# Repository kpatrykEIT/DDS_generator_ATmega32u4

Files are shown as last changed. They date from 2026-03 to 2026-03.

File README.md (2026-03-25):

# DDS_generator_ATmega32u4

Periodic waveform generator project based on Direct Digital Synthesis (DDS). The system utilizes an ATmega32u4 microcontroller and a TLC7524C DAC. Developed low-level firmware in C using direct register manipulation. Designed the PCB in KiCad.

<table>
  <tr>
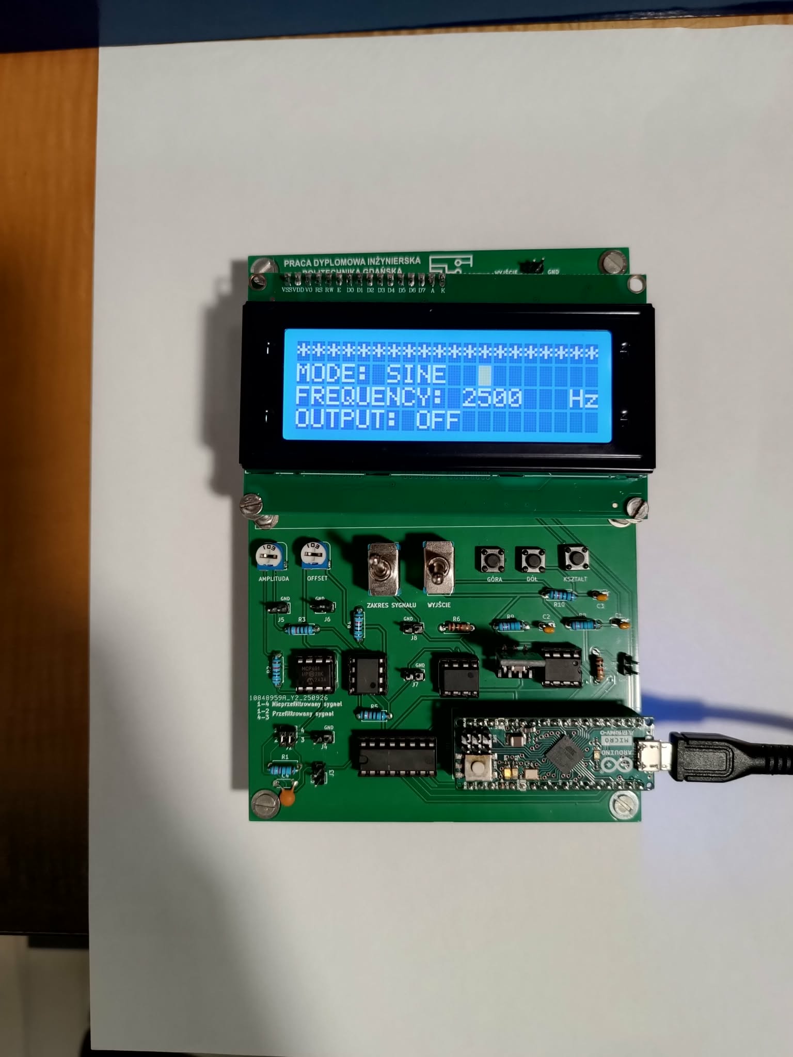
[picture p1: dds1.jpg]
    <td></td>
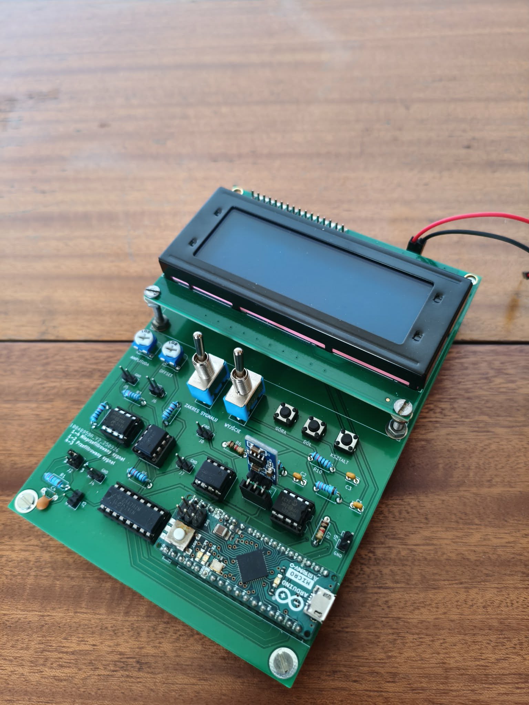
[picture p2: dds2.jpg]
    <td></td>
  </tr>
  <tr>
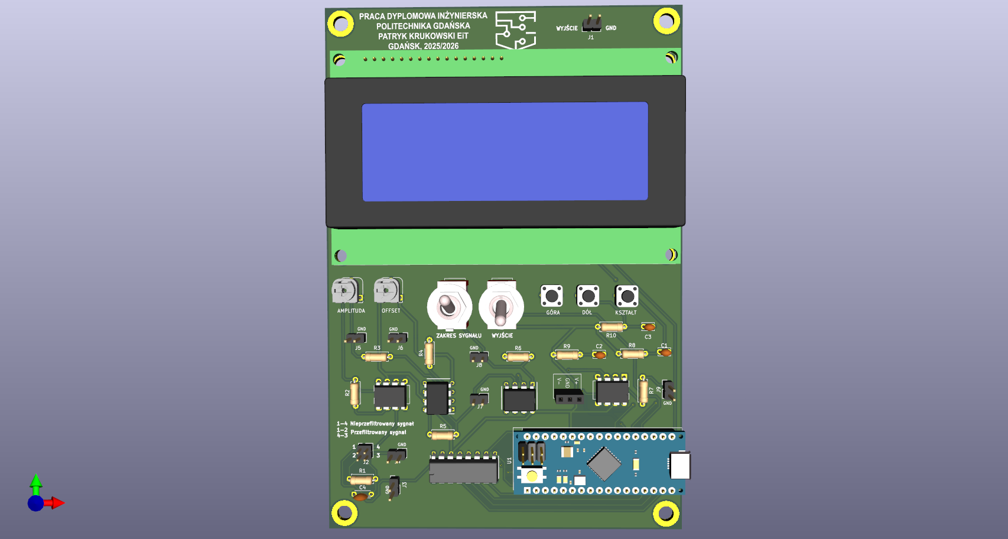
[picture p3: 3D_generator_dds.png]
    <td></td>
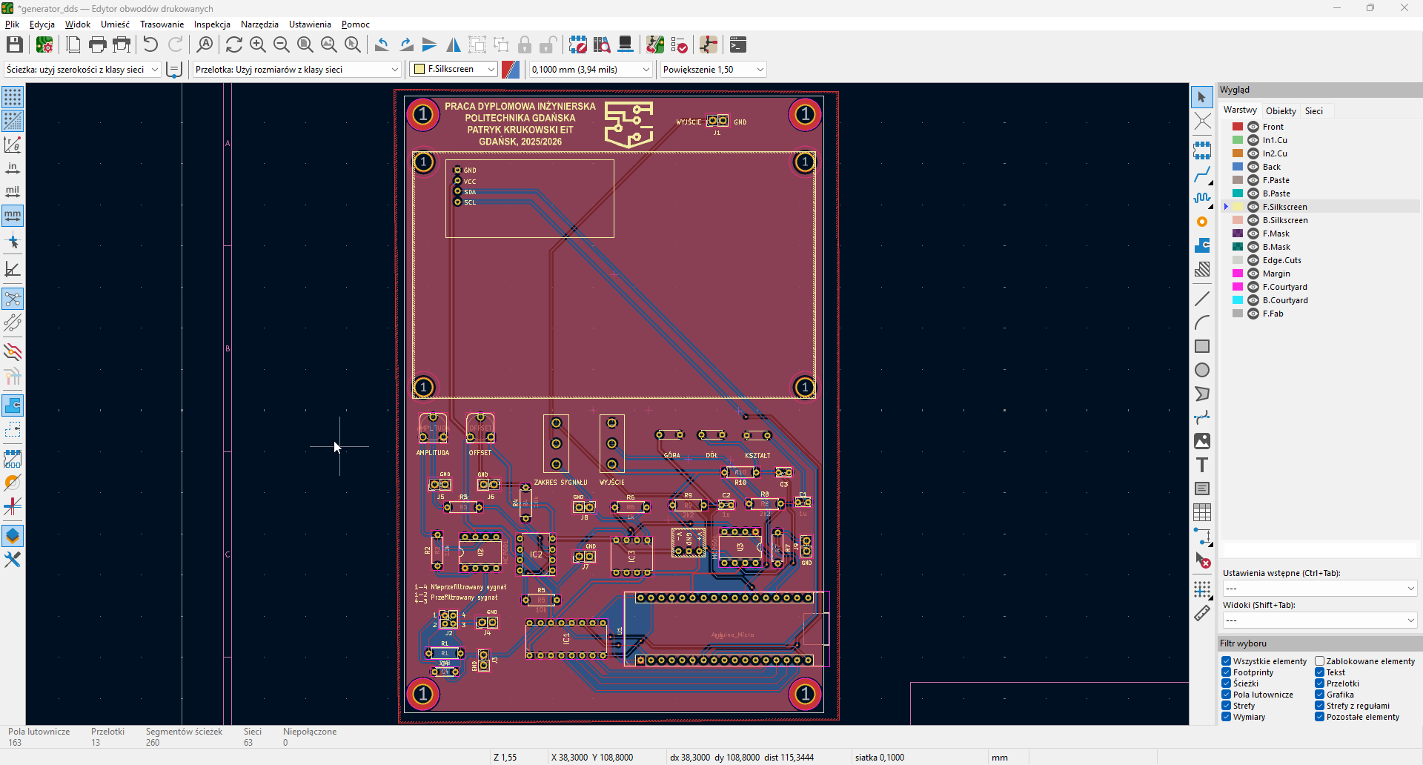
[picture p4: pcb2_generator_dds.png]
  <td></td>
  </tr>
</table>

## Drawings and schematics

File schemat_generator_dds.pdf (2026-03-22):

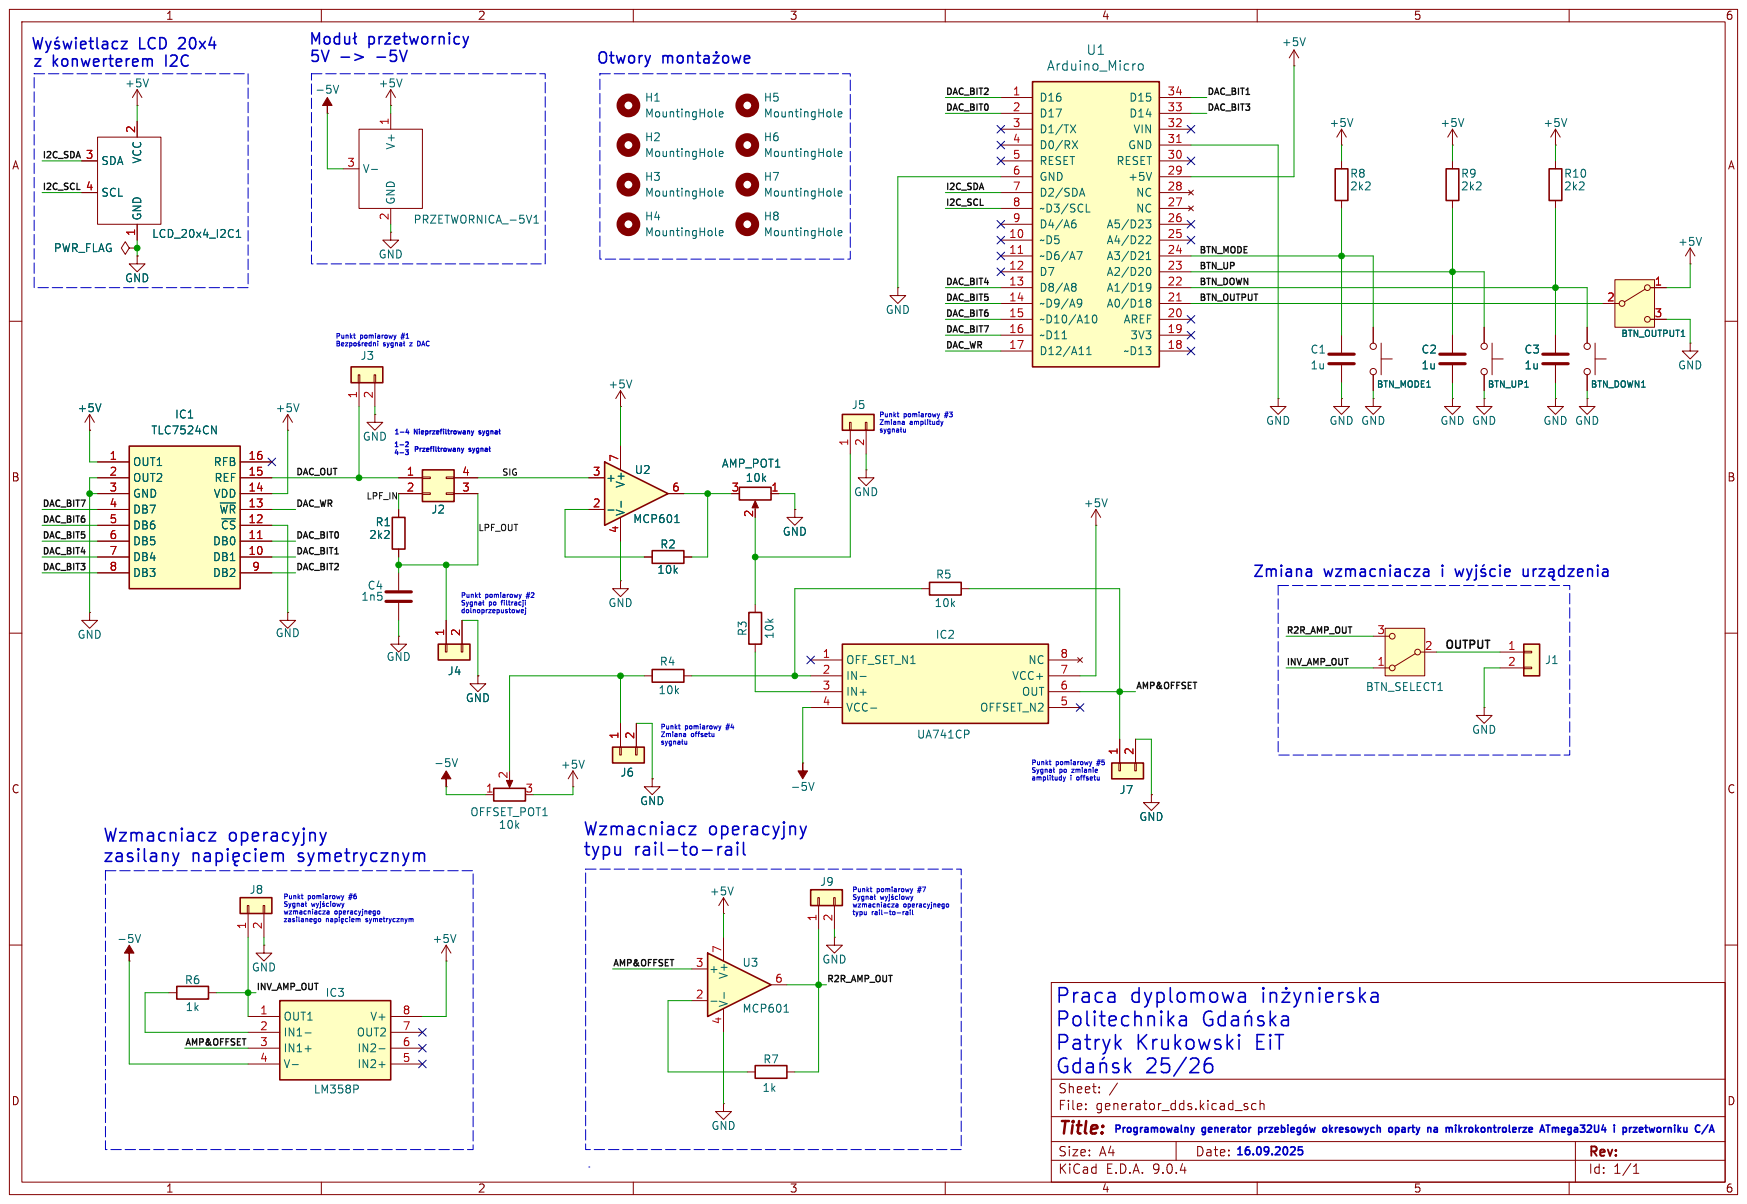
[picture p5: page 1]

typu rail-to-rail

Politechnika þÿGdaDska
Patryk Krukowski EiT
Id: 1/1 Title: File: generator_dds.kicad_sch Sheet: /

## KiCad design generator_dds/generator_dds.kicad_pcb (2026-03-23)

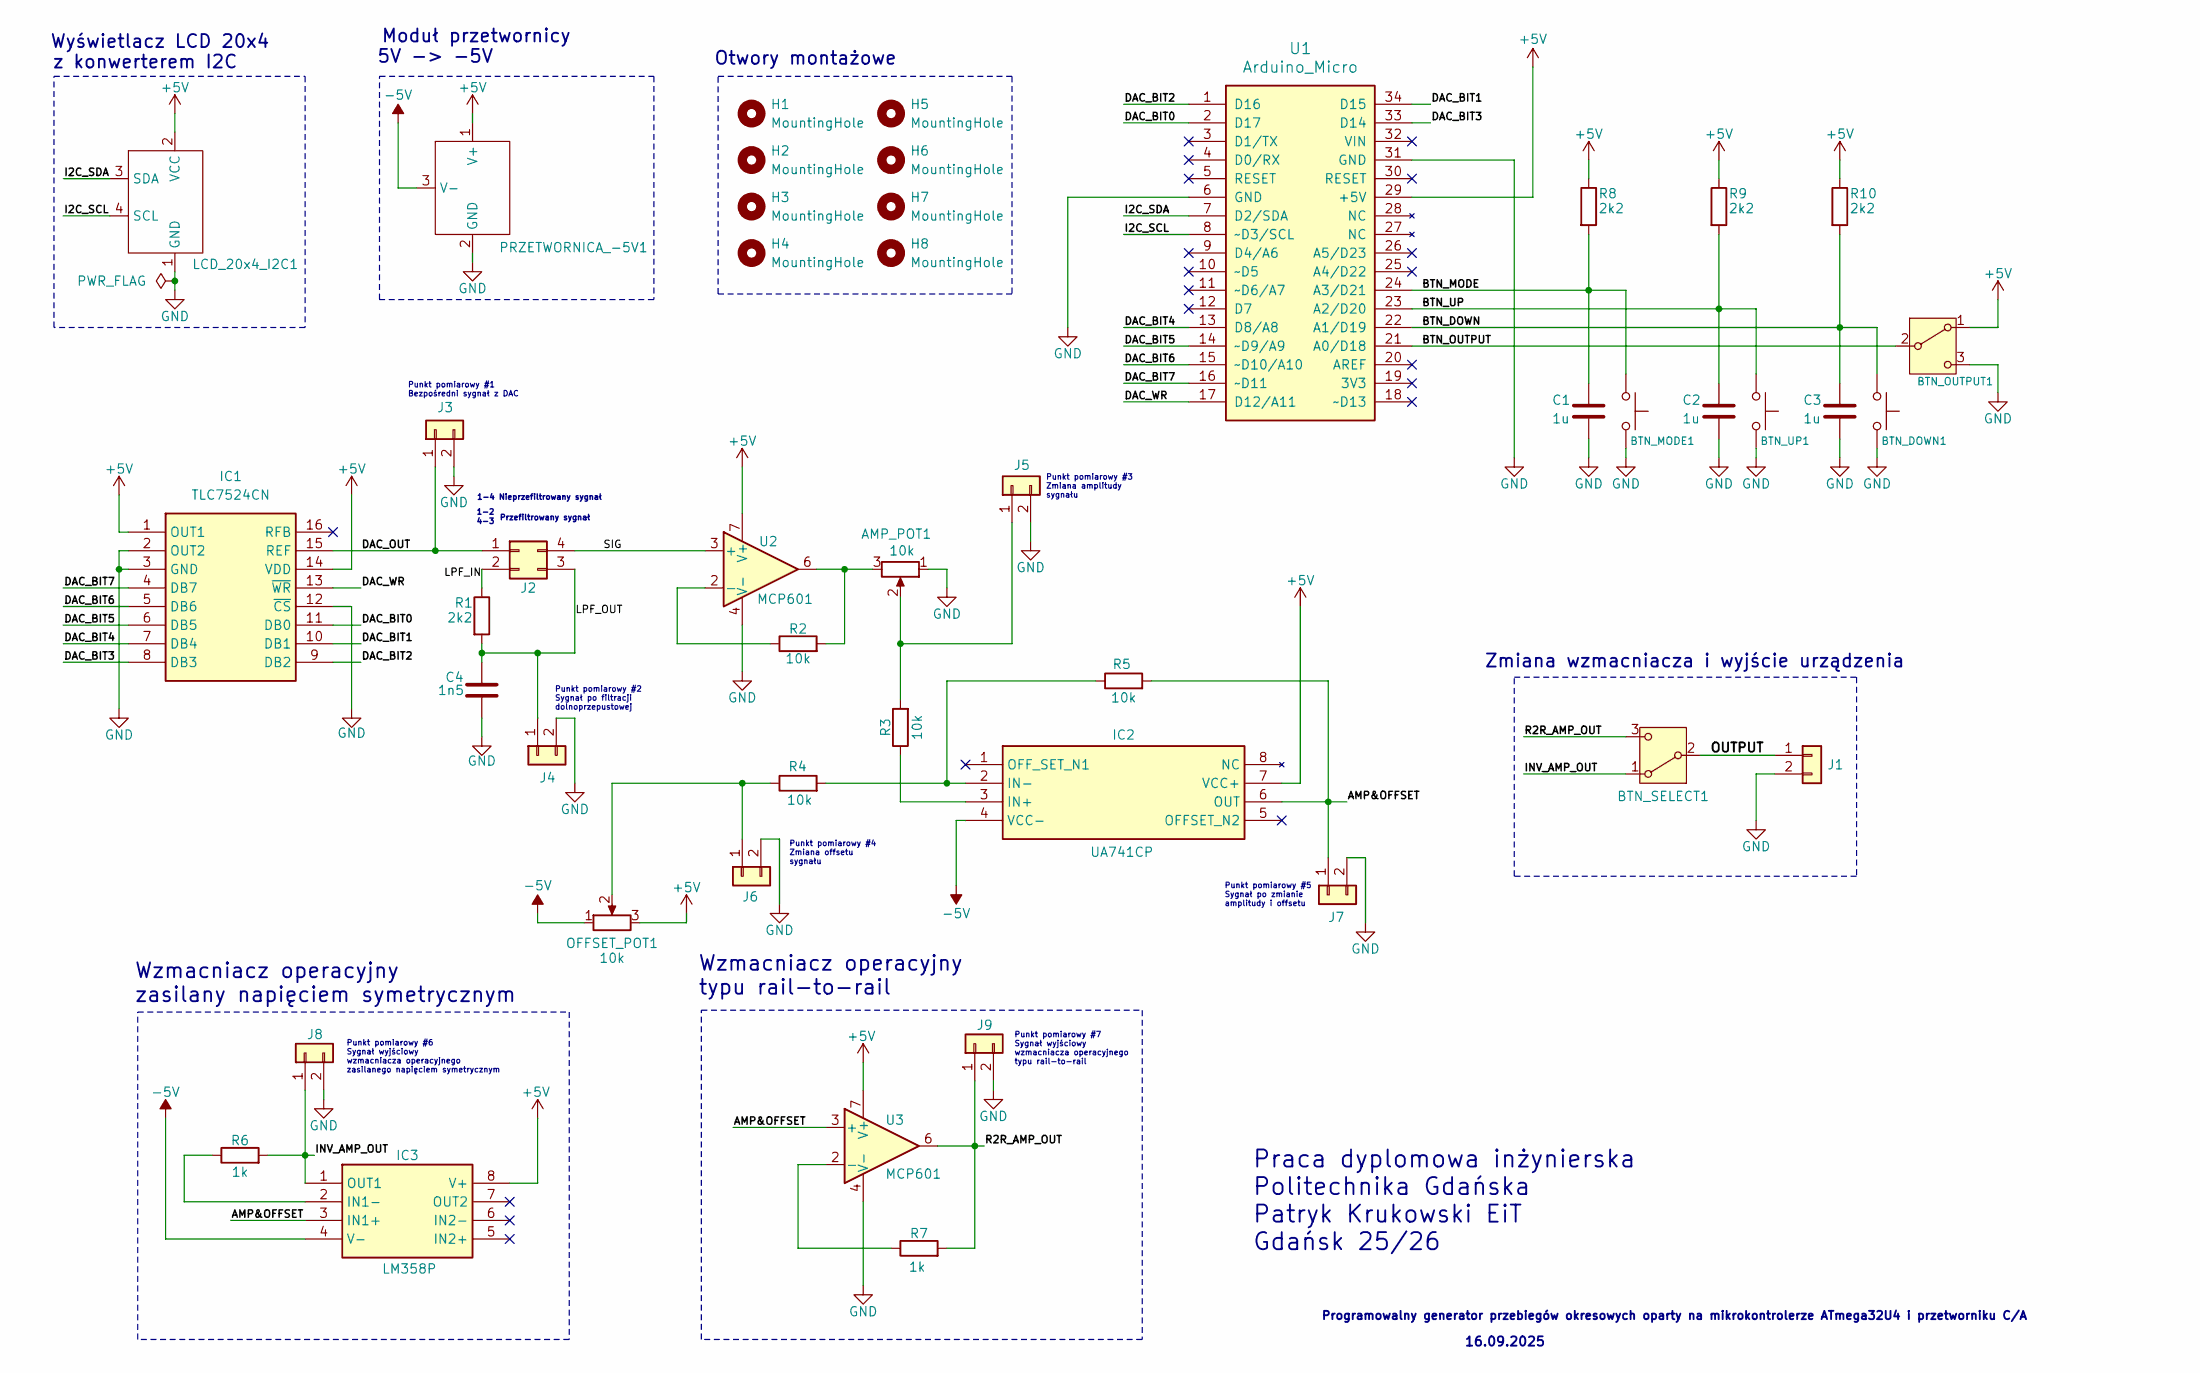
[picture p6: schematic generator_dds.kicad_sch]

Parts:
AMP_POT1: 10k; Potentiometer_Runtron_RM-065_Vertical
BTN_DOWN1: SW_Push; PRZYCISK_2P_5mm
BTN_MODE1: SW_Push; PRZYCISK_2P_5mm
BTN_OUTPUT1: SW_SPDT; PRZELACZNIK_SPDT_5mm
BTN_SELECT1: SW_SPDT; PRZELACZNIK_SPDT_5mm
BTN_UP1: SW_Push; PRZYCISK_2P_5mm
C1, C2, C3: 1u; C_Disc_D3.4mm_W2.1mm_P2.50mm
C4: 1n5; C_Disc_D4.3mm_W1.9mm_P5.00mm
H1, H2, H3, H4, H5, H6, H7, H8: MountingHole; MountingHole_4.3mm_M4_DIN965_Pad
IC1: TLC7524CN; DIP794W53P254L1930H508Q16N; Mouser Part Number 595-TLC7524CN
IC2: UA741CP; DIP794W53P254L959H508Q8N; Mouser Part Number 595-UA741CP
IC3: LM358P; DIP794W53P254L959H508Q8N; Mouser Part Number 595-LM358P
J1, J3, J4, J5, J6, J7, J8, J9: Conn_01x02; PinHeader_1x02_P2.54mm_Vertical
J2: Conn_02x02_Counter_Clockwise; PinHeader_2x02_P2.00mm_Vertical
LCD_20x4_I2C1: LCD_20x4_I2C_TESTfp
OFFSET_POT1: 10k; Potentiometer_Runtron_RM-065_Vertical
PRZETWORNICA_-5V1: PRZETWORNICA_5V
R1, R8, R9, R10: 2k2; R_Axial_DIN0207_L6.3mm_D2.5mm_P7.62mm_Horizontal
R2, R3, R4, R5: 10k; R_Axial_DIN0207_L6.3mm_D2.5mm_P7.62mm_Horizontal
R6, R7: 1k; R_Axial_DIN0207_L6.3mm_D2.5mm_P7.62mm_Horizontal
U1: Arduino_Micro
U2, U3: MCP601; DIP-8_W7.62mm

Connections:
+5V: BTN_OUTPUT1.1 (A), IC1.1 (OUT1), IC1.14 (VDD), IC2.7 (VCC+), IC3.8 (V+), LCD_20x4_I2C1.2 (VCC), OFFSET_POT1.3, PRZETWORNICA_-5V1.1 (V+), R8.1, R9.1, R10.1, U1.29 (+5V), U2.7 (V+), U3.7 (V+); also elsewhere on the board
-5V: IC2.4 (VCC-), IC3.4 (V-), OFFSET_POT1.1, PRZETWORNICA_-5V1.3 (V-); also elsewhere on the board
/AMP&OFFSET: IC2.6 (OUT), IC3.3 (IN1+), J7.1, R5.2, U3.3 (+)
/BTN_DOWN: BTN_DOWN1.1, C3.1, R10.2, U1.22 (A1/D19)
/BTN_MODE: BTN_MODE1.1, C1.1, R8.2, U1.24 (A3/D21)
/BTN_OUTPUT: BTN_OUTPUT1.2 (B), U1.21 (A0/D18); also elsewhere on the board
/BTN_UP: BTN_UP1.1, C2.1, R9.2, U1.23 (A2/D20)
/DAC_BIT0: IC1.11 (DB0), U1.2 (D17)
/DAC_BIT1: IC1.10 (DB1), U1.34 (D15)
/DAC_BIT2: IC1.9 (DB2), U1.1 (D16)
/DAC_BIT3: IC1.8 (DB3), U1.33 (D14)
/DAC_BIT4: IC1.7 (DB4), U1.13 (D8/A8)
/DAC_BIT5: IC1.6 (DB5), U1.14 (~D9/A9)
/DAC_BIT6: IC1.5 (DB6), U1.15 (~D10/A10)
/DAC_BIT7: IC1.4 (DB7), U1.16 (~D11)
/DAC_OUT: IC1.15 (REF), J2.1, J3.1
/DAC_WR: IC1.13 (~WR), U1.17 (D12/A11)
/I2C_SCL: LCD_20x4_I2C1.4 (SCL), U1.8 (~D3/SCL)
/I2C_SDA: LCD_20x4_I2C1.3 (SDA), U1.7 (D2/SDA)
/INV_AMP_OUT: BTN_SELECT1.1 (A), IC3.1 (OUT1), J8.1, R6.2; also elsewhere on the board
/LPF_IN: J2.2, R1.1
/LPF_OUT: C4.1, J2.3, J4.1, R1.2
/OUTPUT: BTN_SELECT1.2 (B), J1.1; also elsewhere on the board
/R2R_AMP_OUT: BTN_SELECT1.3 (C), J9.1, R7.2, U3.6; also elsewhere on the board
/SIG: J2.4, U2.3 (+)
GND: AMP_POT1.1, BTN_DOWN1.2, BTN_MODE1.2, BTN_OUTPUT1.3 (C), BTN_UP1.2, C1.2, C2.2, C3.2, C4.2, IC1.2 (OUT2), IC1.3 (GND), IC1.12 (~CS), J1.2, J3.2, J4.2, J5.2, J6.2, J7.2, J8.2, J9.2, LCD_20x4_I2C1.1 (GND), PRZETWORNICA_-5V1.2 (GND), U1.6 (GND), U1.31 (GND), U2.4 (V-), U3.4 (V-); also elsewhere on the board
unnamed 26: AMP_POT1.3, R2.2, U2.6; also elsewhere on the board
unnamed: IC2.3 (IN+), R3.1
unnamed: IC2.2 (IN-), R4.2, R5.1
unnamed: IC3.2 (IN1-), R6.1
unnamed 30: AMP_POT1.2, J5.1, R3.2; also elsewhere on the board
unnamed 31: J6.1, OFFSET_POT1.2, R4.1; also elsewhere on the board
unnamed: R2.1, U2.2 (-)
unnamed: R7.1, U3.2 (-)

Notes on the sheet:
Przefiltrowany sygnał
1-4 Nieprzefiltrowany sygnał
Wyświetlacz LCD 20x4
Otwory montażowe
Wzmacniacz operacyjny typu rail-to-rail
5V -> -5V
Punkt pomiarowy #7 Sygnał wyjściowy wzmacniacza operacyjnego typu rail-to-rail
Punkt pomiarowy #1 Bezpośredni sygnał z DAC
1-2
Punkt pomiarowy #2 Sygnał po filtracji dolnoprzepustowej
Praca dyplomowa inżynierska Politechnika Gdańska Patryk Krukowski EiT Gdańsk 25/26
16.09.2025
z konwerterem I2C
Moduł przetwornicy
Punkt pomiarowy #5 Sygnał po zmianie amplitudy i offsetu
Punkt pomiarowy #3 Zmiana amplitudy sygnału
Punkt pomiarowy #4 Zmiana offsetu sygnału
4-3
Zmiana wzmacniacza i wyjście urządzenia
Programowalny generator przebiegów okresowych oparty na mikrokontrolerze ATmega32U4 i przetworniku C/A
Punkt pomiarowy #6 Sygnał wyjściowy wzmacniacza operacyjnego zasilanego napięciem symetrycznym
Wzmacniacz operacyjny zasilany napięciem symetrycznym

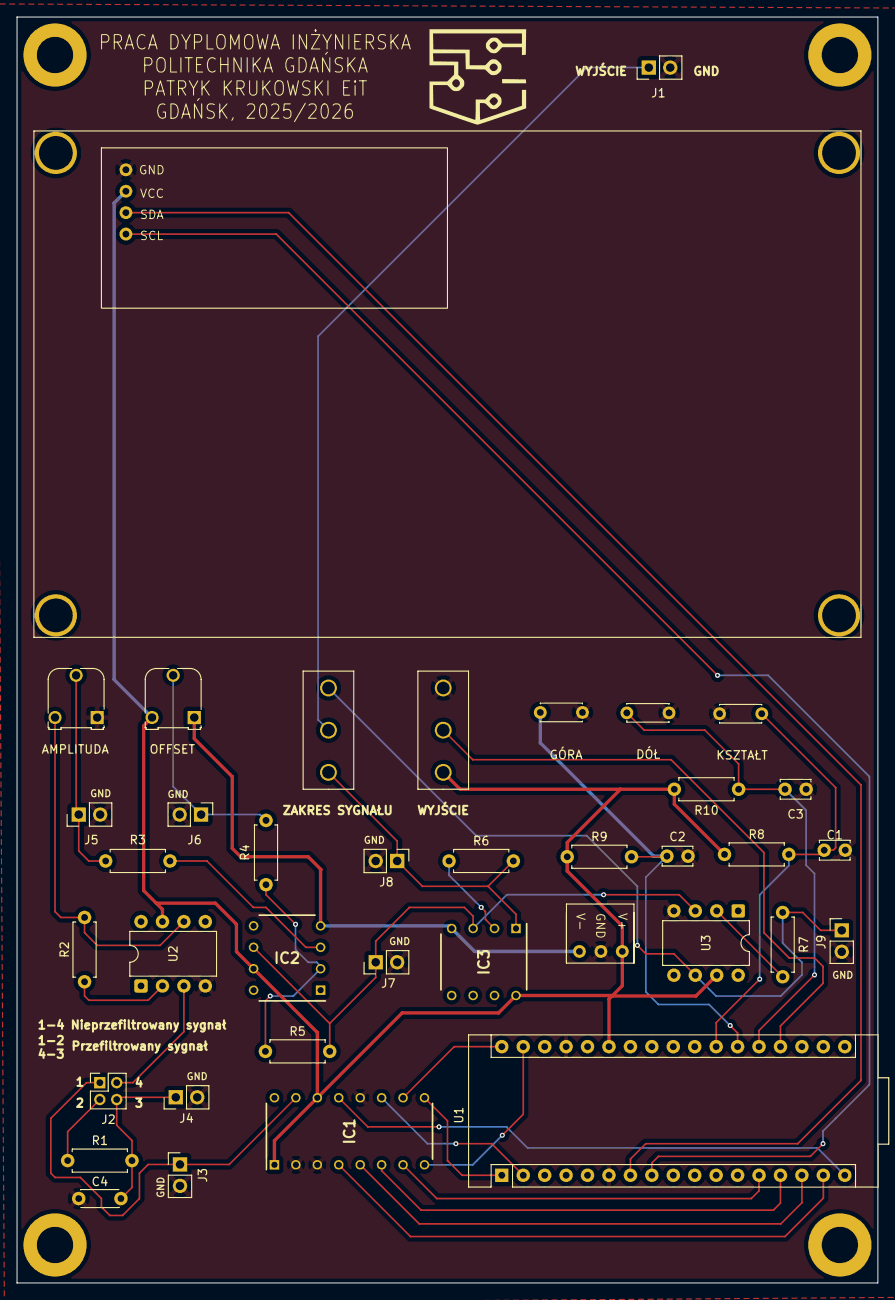
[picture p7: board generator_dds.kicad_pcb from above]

Board: 4 copper layers, 102.0 x 150.0 mm, 46 parts (0 on the bottom side), 34 nets.

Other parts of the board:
AMPLITUDA: 10k; Potentiometer_Runtron_RM-065_Vertical
OFFSET: 10k; Potentiometer_Runtron_RM-065_Vertical
WYJŚCIE: SW_SPDT; PRZELACZNIK_SPDT_5mm
ZAKRES SYGNAŁU: SW_SPDT; PRZELACZNIK_SPDT_5mm

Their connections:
+5V: OFFSET.3, WYJŚCIE.1 (A); also elsewhere on the board
-5V: OFFSET.1; also elsewhere on the board
/BTN_OUTPUT: WYJŚCIE.2 (B); also elsewhere on the board
/INV_AMP_OUT: ZAKRES SYGNAŁU.1 (A); also elsewhere on the board
/OUTPUT: ZAKRES SYGNAŁU.2 (B); also elsewhere on the board
/R2R_AMP_OUT: ZAKRES SYGNAŁU.3 (C); also elsewhere on the board
GND: AMPLITUDA.1, WYJŚCIE.3 (C); also elsewhere on the board
unnamed 26: AMPLITUDA.3; also elsewhere on the board
unnamed 30: AMPLITUDA.2; also elsewhere on the board
unnamed 31: OFFSET.2; also elsewhere on the board

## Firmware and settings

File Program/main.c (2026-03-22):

/*
* File: main.c 
*
* Created: 31.05.2025 11:22:55
* Author : Patryk Krukowski 
*/

#include "main.h"

// Zmienne dla LCD
// 1 - Sinusoidalny
// 2 - Prostokatny
// 3 - Trojkatny
// 4 - Piloksztaltny

volatile uint8_t mode = 1;
volatile bool output = false;

// Zmienne dla DDS

volatile int32_t DDS_fout = 100; 
volatile uint32_t DDS_phaseACC = 0; 
volatile uint8_t DDS_index = 0;
volatile uint32_t DDS_tunningWord = 0;
uint32_t DDS_fsample = 100000; // Hz
const uint8_t DDS_preskaler = 8;

int main(void)
{	
	avr_init();
	timer1_init();
	
	// LCD inicjalizacja
	
	i2c_master_init(I2C_SCL_FREQUENCY_400);
	lq_init(0x27, 20, 4, LCD_5x8DOTS);
	LiquidCrystalDevice_t device = lq_init(0x27, 20, 4, LCD_5x8DOTS);
	lq_turnOnBacklight(&device);
	display_author_info(device);
	//_delay_ms(2000);
	//lq_clear(&device);
	
	sei();
	while(1){
		
		if(output)
		{
			PORTF |= (1 << LED_GREEN);
			PORTF &= ~(1 << LED_RED);
			TIMSK1 |= (1 << OCIE1A); // wlacz przerwania Timera1
			
		}
		if(output == false)
		{
			PORTF |= (1 << LED_RED);
			PORTF &= ~(1 << LED_GREEN);
			TIMSK1 &= ~(1 << OCIE1A); // wylacz przerwania Timera1
			
			// Zmiana wyjsciowej czestotliwosci
			if(BTN_PRESSED(PINF, BTN_UP))
			{
				DDS_fout += 100; // + 100 Hz
				if(DDS_fout > 15000)
				{
					DDS_fout = 15000;
				}
				//_delay_ms(50);
				
			}
			if(BTN_PRESSED(PINF, BTN_DOWN))
			{
				DDS_fout -= 100; // - 100 Hz		
				if(DDS_fout < 0)
				{
					DDS_fout = 0;
				}
				//_delay_ms(50);
			}
			DDS_tunningWord = (pow(2,32)*DDS_fout)/DDS_fsample;
			// Zmiana ksztaltu przebiegu
			if(BTN_PRESSED(PINF,BTN_MODE) && output == false)
			{
				mode ++;
				if(mode > 4)
				{
					mode = 1;
				}
			}
		}
		if(BTN_PRESSED(PINF, BTN_OUTPUT))
		{
			output = false;
		}
		if(!BTN_PRESSED(PINF, BTN_OUTPUT))
		{
			output = true;
		}
		main_menu(device, mode, output, DDS_fout);
	}
}

// Wysylanie probki do DACa

ISR(TIMER1_COMPA_vect)
{
	if(BTN_PRESSED(PINF, BTN_OUTPUT))
	{
		TIMSK1 &= ~(1 << OCIE1A); // wylacz przerwania Timera1
	}
	DDS_phaseACC += DDS_tunningWord;
	DDS_index = (DDS_phaseACC >> 24);
	if(mode == 1)
	{
		 DAC_OUTPUT = sin_wave256[DDS_index];
	}
	if(mode == 2)
	{
		DAC_OUTPUT = square_wave256[DDS_index];
	 
	}
	if(mode == 3)
	{
		DAC_OUTPUT = triangle_wave256[DDS_index];
	} 
	if(mode == 4)
	{
		 DAC_OUTPUT = sawtooth_wave256[DDS_index];
	}
}
inline void timer1_init(void)
{
	TCCR1B |= (1 << WGM12) | (1 << CS11); // CTC, 8 preskaler
	OCR1A  = (F_CPU/(DDS_preskaler*DDS_fsample)) - 1;
}

	
// Inicjalizacja wejsc/wyjsc
	
inline void avr_init(void)
{
	// Wylacz przerwania USB
	UDIEN = 0;
	// Przyciski jako wejscia
	DDRF &= ~(1 << BTN_MODE);
	DDRF &= ~(1 << BTN_UP);
	DDRF &= ~(1 << BTN_DOWN);
	DDRF &= ~(1 << BTN_OUTPUT);
	// PORTB jako wyjscia dla C/A
	DDRB |= (1 << DAC_DB0);
	DDRB |= (1 << DAC_DB1);
	DDRB |= (1 << DAC_DB2);
	DDRB |= (1 << DAC_DB3);
	DDRB |= (1 << DAC_DB4);
	DDRB |= (1 << DAC_DB5);
	DDRB |= (1 << DAC_DB6);
	DDRB |= (1 << DAC_DB7);
	DDRD |= (1 << DAC_WR);
}

// Informacje o autorze

void display_author_info(struct LiquidCrystalDevice_t device)
{
	lq_setCursor(&device, 0 , 2);
	lq_print(&device, "PRACA DYPLOMOWA");
	lq_setCursor(&device, 1 , 4);
	lq_print(&device, "INZYNIERSKA");
	lq_setCursor(&device, 2 , 0);
	lq_print(&device, "Patryk Krukowski EiT");
	lq_setCursor(&device, 3 , 4);
	lq_print(&device, "GDANSK, 2026");
	_delay_ms(3000);
	lq_clear(&device);
}

// Menu glowne

void main_menu(struct LiquidCrystalDevice_t device, uint8_t mode, bool output, int32_t fout)
{
	char fout_buffer[32];
	sprintf(fout_buffer,"%-5lu",fout);
	lq_setCursor(&device,0,0);
	lq_print(&device,"********************");
	lq_setCursor(&device, 1, 0);
	lq_print(&device, "MODE: ");
	lq_setCursor(&device, 2, 0);
	lq_print(&device, "FREQUENCY: ");
	lq_setCursor(&device, 2, 11);
	lq_print(&device, fout_buffer);
	lq_setCursor(&device, 2, 18);
	lq_print(&device, "Hz");
	lq_setCursor(&device, 3,0);
	lq_print(&device, "OUTPUT: ");
	if(output)
	{
		lq_setCursor(&device,3,8);
		lq_print(&device, "ON ");
	}
	if(output == false)
	{
		lq_setCursor(&device,3,8);
		lq_print(&device, "OFF ");
	}
	if(mode == 1)
	{
		lq_setCursor(&device, 1, 6);
		lq_print(&device, "SINE      ");
		lq_turnOnBlink(&device);
		_delay_ms(100);
		lq_turnOffBlink(&device);
		//lq_setCursor(&device, 1, 10);
		//lq_print(&device,"     ");
	}
	if(mode == 2)
	{
		lq_setCursor(&device, 1, 6);
		lq_print(&device, "SQUARE    ");
		lq_turnOnBlink(&device);
		_delay_ms(100);
		lq_turnOffBlink(&device);
	}
	if(mode == 3)
	{
		lq_setCursor(&device, 1, 6);
		lq_print(&device, "TRIANGLE    ");
		lq_turnOnBlink(&device);
		_delay_ms(100);
		lq_turnOffBlink(&device);
	}
	if(mode == 4)
	{
		lq_setCursor(&device, 1, 6);
		lq_print(&device, "SAWTOOTH   ");
		lq_turnOnBlink(&device);
		_delay_ms(100);
		lq_turnOffBlink(&device);
	}
}

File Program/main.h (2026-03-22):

/*
 * File: main.h
 *
 * Created: 02.06.2025 17:09:30
 *  Author: Patryk Krukowski
 */ 


#ifndef MAIN_H_
#define MAIN_H_

// BIBLIOTEKI

#include <avr/io.h>
#include <avr/interrupt.h>
#include <util/delay.h>
#include <stdint.h>
#include <stdio.h>
#include <stdlib.h>
#include <stdbool.h>
#include <math.h>
#include "sin_wave.h"
#include "sawtooth_wave.h"
#include "square_wave.h"
#include "triangle_wave.h"
#include "i2c_master.h"
#include "liquid_crystal_i2c.h"

// PRZYCISKI

#define BTN_MODE	PF4		// zmien ksztalt przebiegu
#define BTN_UP		PF5		// zwieksz czestotliwosc
#define BTN_DOWN	PF6		// zmniejsz czestotliwosc
#define BTN_OUTPUT	PF7		// wlacz/wylacz wyjscie generatora

// PRZETWORNIK C/A


#define DAC_WR	PD6
#define DAC_DB0 PB0
#define DAC_DB1 PB1
#define DAC_DB2 PB2
#define DAC_DB3 PB3
#define DAC_DB4 PB4
#define DAC_DB5 PB5
#define DAC_DB6 PB6
#define DAC_DB7 PB7
#define DAC_OUTPUT	PORTB


// MAKRA

#define BTN_PRESSED(PIN,BIT)	(!((PIN) & (1 << (BIT))))

// FUNKCJE

inline void avr_init(void);
void display_author_info(struct LiquidCrystalDevice_t device);
void main_menu(struct LiquidCrystalDevice_t device, uint8_t mode, bool output, int32_t fout);
inline void timer1_init(void);

#endif /* MAIN_H_ */
